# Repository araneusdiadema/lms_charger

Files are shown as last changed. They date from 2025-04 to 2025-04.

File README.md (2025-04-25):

# LMS Charger

## Introduction 
LMS Charger is a miniature module with USB-C designed for charging
Li-Po bateries. I designed this module while working on other projects
where I needed small Li-Po battery and available solutions were too big
for the application. I also needed some other features.

## Features
- USB-C input - for charging the battery
- MCP73833 - battery charger with selectable current up to 500mA,
  selectable resistor is used to set the current.
- Power Path - for powering the output from the USB, while the
  battery is being charged.

## Safety
 - This module was designed for Li-Po batteries with protection circuit
   inside the package, don't use with unprotected batteries. Li-Ion
   can be used, but use those with protection circuit.
 - The output of module is either 5V or VBAT, depending on whether the
   USB is connected. Connect only with electronics that can handle
   this voltage range.

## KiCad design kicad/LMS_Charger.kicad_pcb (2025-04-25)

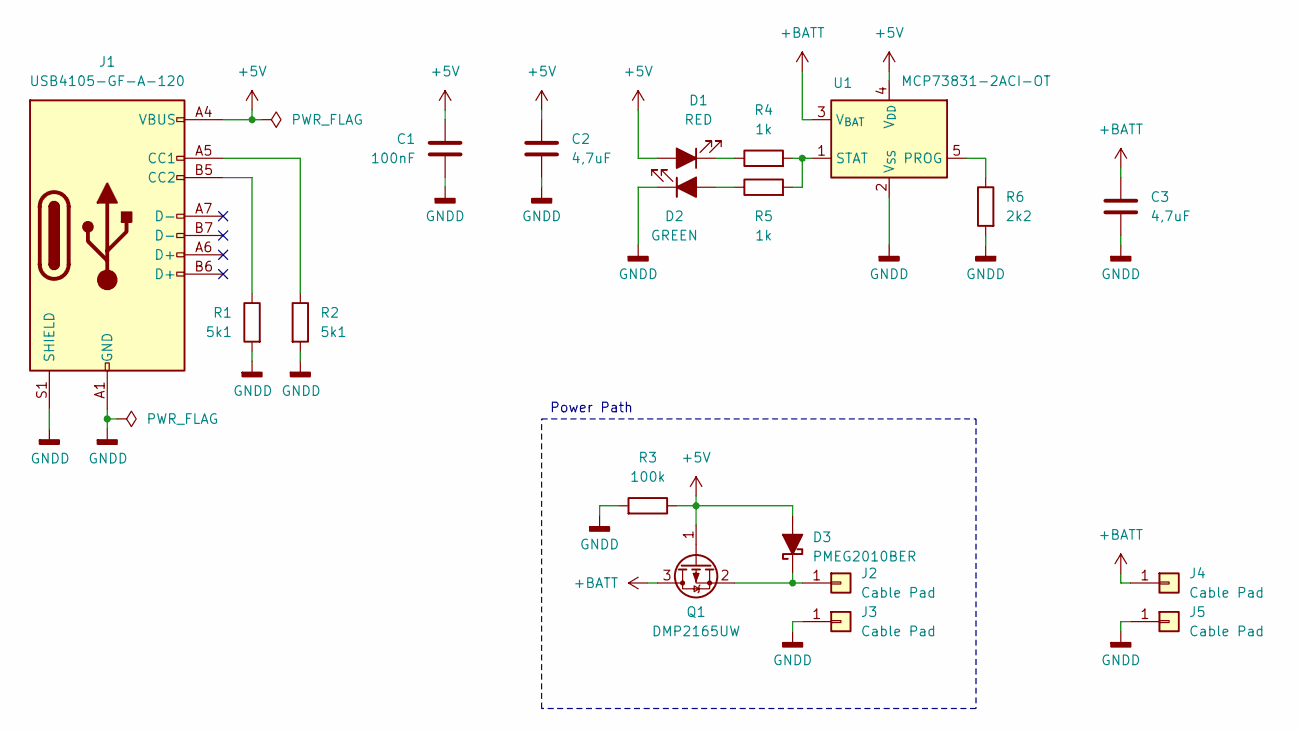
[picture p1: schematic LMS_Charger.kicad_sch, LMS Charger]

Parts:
C1: 100nF; C_0603_1608Metric
C2, C3: 4,7uF; C_0603_1608Metric
D1: RED; LED_0603_1608Metric
D2: GREEN; LED_0603_1608Metric
D3: PMEG2010BER; Nexperia_CFP3_SOD-123W
J1: USB4105-GF-A-120; USB_C_Receptacle_GCT_USB4105-xx-A_16P_TopMnt_Horizontal
J2, J3, J4, J5: Cable Pad; SMD_Cable_pad_1
Q1: DMP2165UW; SOT-323_SC-70
R1, R2: 5k1; R_0603_1608Metric
R3: 100k; R_0603_1608Metric
R4, R5: 1k; R_0603_1608Metric
R6: 2k2; R_0603_1608Metric
U1: MCP73831-2ACI-OT; SOT-23-5

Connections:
+5V: C1.1, C2.1, D1.2 (A), D3.2 (A), J1.A4 (VBUS), J1.A9 (VBUS), J1.B4 (VBUS), J1.B9 (VBUS), Q1.1 (G), R3.1, U1.4 (V_{DD})
+BATT: C3.1, J4.1, Q1.3 (D), U1.3 (V_{BAT})
GNDD: C1.2, C2.2, C3.2, D2.1 (K), J1.A1 (GND), J1.A12 (GND), J1.B1 (GND), J1.B12 (GND), J1.S1 (SHIELD), J3.1, J5.1, R1.2, R2.2, R3.2, R6.2, U1.2 (V_{SS})
unnamed: D1.1 (K), R4.1
unnamed: D2.2 (A), R5.1
unnamed: D3.1 (K), J2.1, Q1.2 (S)
unnamed: J1.A5 (CC1), R2.1
unnamed: J1.B5 (CC2), R1.1
unnamed: R6.1, U1.5 (PROG)
unnamed: R4.2, R5.2, U1.1 (STAT)

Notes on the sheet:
Power Path

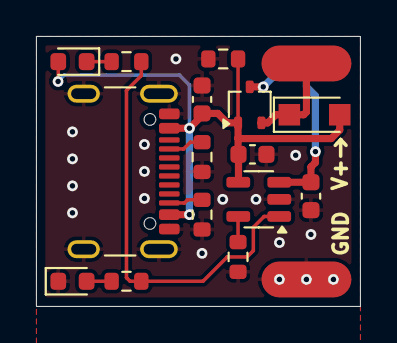
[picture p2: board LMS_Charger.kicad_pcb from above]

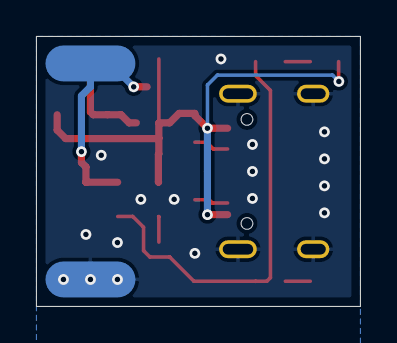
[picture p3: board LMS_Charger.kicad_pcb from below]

Board: 2 copper layers, 18.0 x 15.0 mm, 19 parts (2 on the bottom side), 10 nets.

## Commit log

2025-04-25 draft(kicad): Added first draft of the electronics
    [LMS_Charger.kicad_pcb, LMS_Charger.kicad_sch]
2025-04-25 feat(lower_current): Created light version of charger for small bateries
    [LMS_Charger.kicad_pcb, LMS_Charger.kicad_sch]
2025-04-25 fix(values): Minor updates in components and footprints
    [LMS_Charger.kicad_pcb, LMS_Charger.kicad_sch]
2025-04-25 fix(power_path): Solved problem with leaking current through reverse diode, adjusted LED resistors
    [LMS_Charger.kicad_pcb, LMS_Charger.kicad_sch]
2025-04-25 fab(gerber): Generated gerber files for manufactiring
